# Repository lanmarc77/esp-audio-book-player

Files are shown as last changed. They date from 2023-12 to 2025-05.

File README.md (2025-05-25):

# TINAMP: An ESP32 based audio book player build from existing electronics modules
TINAMP: **T**his **I**s **N**ot **A** **M**usic **P**layer.  
  
This is a device that is meant to play non-DRM audio books from SD cards and has the following features:  

- folder based audio book player, one folder contains all files of one audio book
- multiple audio books supported (currently max. 9999 on one SD card with presorted index)
- sorting of audio book names and audio book files by ASCII name (see limitations of sorting below)
- saves audio book listening position and resumes for each audio book
- supports huge single file audio books, e.g. a 20hrs long singe file audio book
- file formats AMR-WB, MP3 and OGG
- ASCII character based menu driven UI for 16x4 character screen
- single rotary encoder navigation
- sleep timer 1...480min, wakeup timer 1min...24hr
- play speed settings from 0.5...2.5 in 0.05 steps (saved individually for each audio book)
- audio equalizer (saved individually for each audio book)
- endless auto repeat mode of selected audio book
- auto power off
- firmware upgrades from SD card
- based on pure esp-idf + esp-adf
- plays 50hrs+ with 2800mAh 18650 battery
- does not need nor use any wireless connection
- does not track the user in any way
- charging via USB-C
- endless options of integrations with speakers/cases
  
It tries to follow the design principle of
[doing one thing and doing that well](https://en.wikipedia.org/wiki/Unix_philosophy).
  
# The working prototypes
development board:
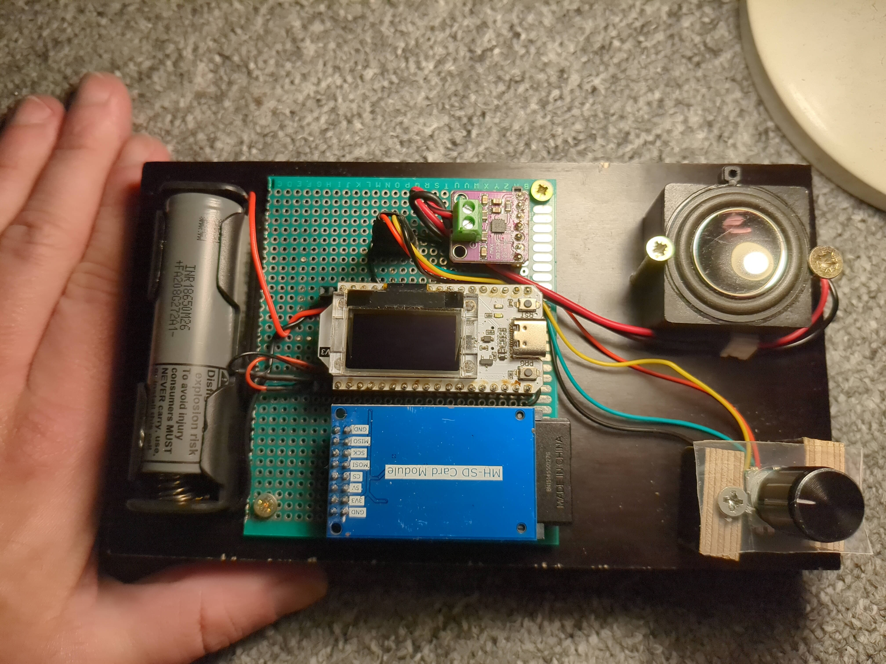
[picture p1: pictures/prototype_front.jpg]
  
  
integrated in an old speaker that otherwise might have landed in the trash:  
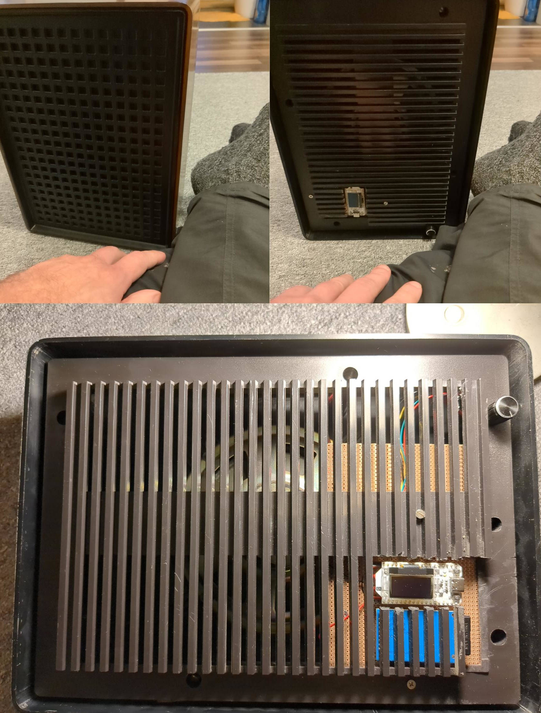
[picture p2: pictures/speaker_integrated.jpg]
  
  
the current portable/smaller prototype version (based on Hammond RL6215 case):  
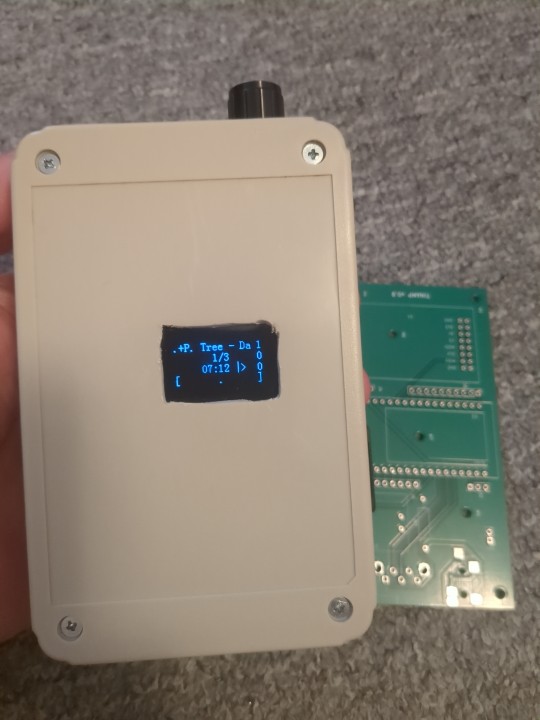
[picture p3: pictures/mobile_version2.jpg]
  
  
first 3d print prototype with 80s vibes:  
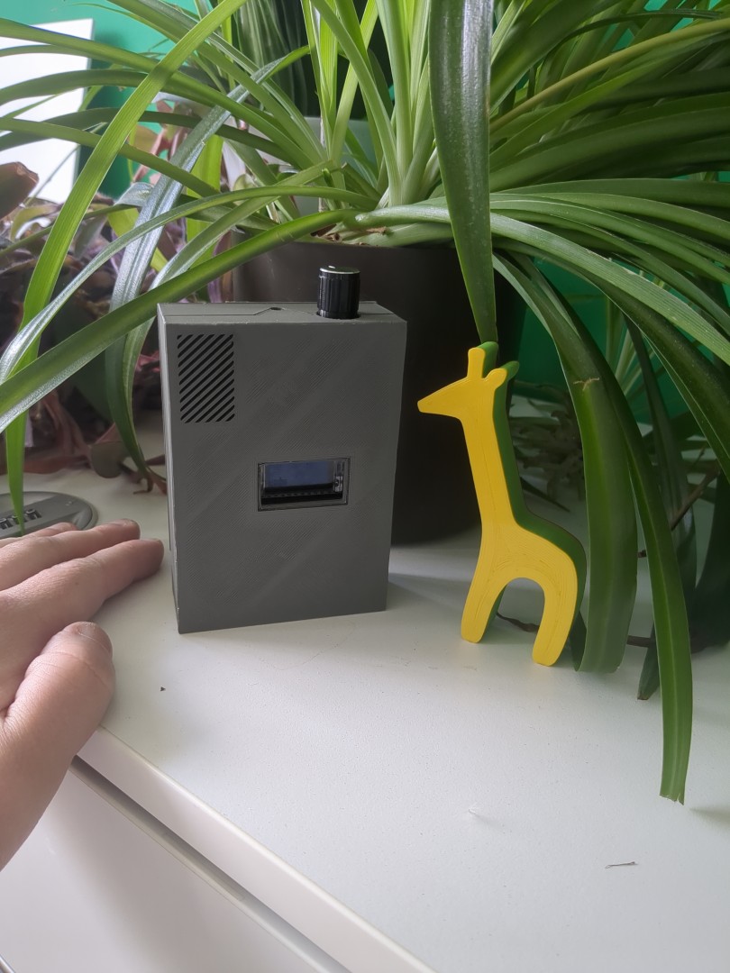
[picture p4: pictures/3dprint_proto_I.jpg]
  
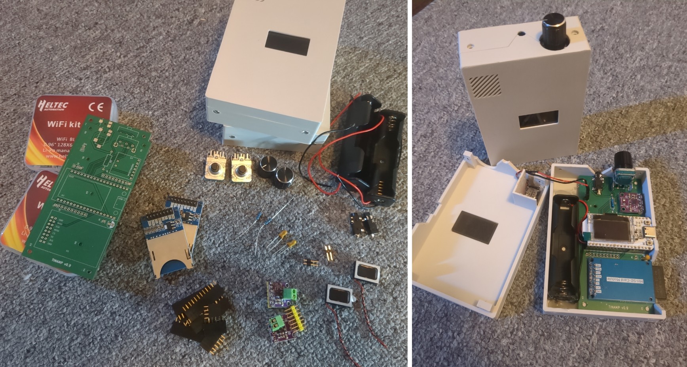
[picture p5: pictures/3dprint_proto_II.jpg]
  
  
[first POC (proof of concept)](pictures/first_poc.jpg)
  
# Why?
By the time of this writing (2023) one really needs to search hard to find an offline only non tracking audio book player that is
able to play files from huge SD cards and at the same time sorts the files based on their name and remembers and
resumes the last listening position.  
Many people nowadays will use subscription services with corresponding apps on their smartphone. These services
and the apps usually track the users build profiles suggest new audio books sell ads and more. Services like these can be canceled at any time. May it be for politics or economic reasons. They usually do not allow you to own the audio book but only sell a license to listen at it for as long as the company exists or is allowed to do business with you.  
I have an audio book collection that I created by only buying if I can download the files or copy them e.g. from a CD to keep them. Without any DRM.  
All my audio books are converted to and then stored in AMR-WB as for me the quality with 24kBit/s mono is good enough.
This shrinks an MP3 file to approx. 1/10ths when using AMR-WB and also makes the backup cheap. One CD with AMR-WB can hold 60hrs, a DVD 350hrs, a 25GB BD-R 2000hrs+.  
A 256GB SD card can hold around 2 years and 9 months of continuous listening in AMR-WB. Multiple SD cards can hold enough listening material for a life time.  
Using existing electronics hardware modules and the software of this repository I can now build a device that just plays my audio books. Not more, not less. And it most likely will do so in 30years assuming nothing breaks.
There are still 30yrs+ old Nintendo Gameboys that work like a charm and are being refurbished.  
Additionally I can change the behavior of the software as I like. The whole development environment works offline and can also be installed in an offline virtual machine and will still be able to compile even if the hardware manufacturer of the main controller board does not exist anymore.  
  
# Videos
Download and watch:  
[Scenario1](https://github.com/lanmarc77/esp-audio-book-player/raw/main/videos/scenario1.mp4): normal operation  
[Scenario2](https://github.com/lanmarc77/esp-audio-book-player/raw/main/videos/scenario2.mp4): seeking  
[Scenario3](https://github.com/lanmarc77/esp-audio-book-player/raw/main/videos/scenario3.mp4): sorting  
[Scenario4](https://github.com/lanmarc77/esp-audio-book-player/raw/main/videos/scenario4.mp4): auto bookmarks  
[Scenario5](https://github.com/lanmarc77/esp-audio-book-player/raw/main/videos/scenario5.mp4): sleep timer  
[Scenario6](https://github.com/lanmarc77/esp-audio-book-player/raw/main/videos/scenario6.mp4): wakeup timer  
[Scenario7](https://github.com/lanmarc77/esp-audio-book-player/raw/main/videos/scenario7.mp4): firmware upgrade  
[Scenario8](https://github.com/lanmarc77/esp-audio-book-player/raw/main/videos/scenario8.mp4): play speed, equalizer, repeat mode  
  
# Hardware
The build only needs a few components that are manufactured by companies in mass and therefore cheap.  
For PCB based components the schematics are available in the module datasheets folder.  
  
**Main controller board:**  
The main controller board is a Heltec WiFi Kit 32 V3. It was chosen because it has a very small deep sleep
current of about 10µA. I measured 15µA with nothing connected to it. Still very good. It already comes with
the circuitry to connect and charge a rechargeable battery as well as the possibility to disconnect other
components from power by using a software programmable power pin (Ve).  
Finally an OLED display is also already available for the UI.  
Be aware that you buy V3 of this board version as it has the low deep sleep current. Otherwise your battery
looses way too much energy even if you do not use the player. Additionally verify that you also get a fitting
battery cable.  
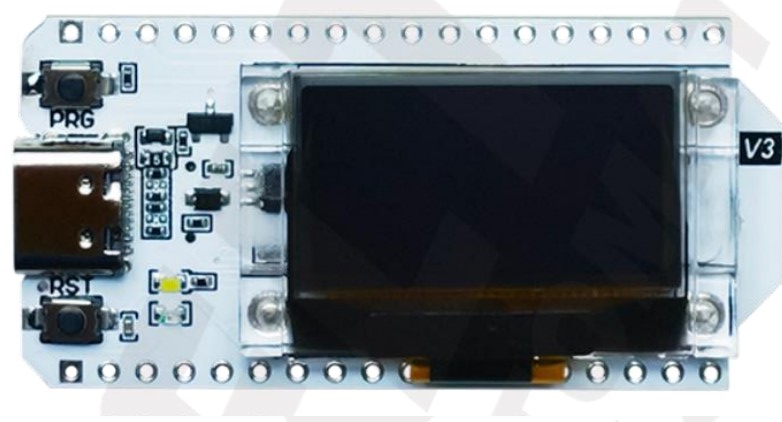
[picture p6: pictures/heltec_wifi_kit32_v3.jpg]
  
Typical price in Germany incl. tax (2023): 20€. 
  
**I²S digital analog audio converter**  
Currently only a MAX98357A based converter has been tested extensively. Also an UDA1334A and PCM5102 were
tested and they worked. Both of these stereo DACs needed around 10-15mA more current which will reduce the system
runtime.
The MAX98357A already contains an amplifier to directly connect it to a speaker and get a usable volume out
of it.  
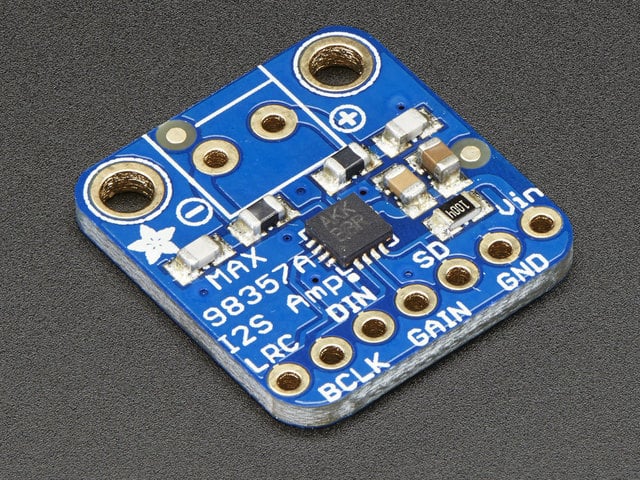
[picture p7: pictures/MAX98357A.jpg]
  
Typical price in Germany incl. tax (2023): 8€. 
  
**SD card holder**  
I still had old big SD cards laying around so I started with a big SD card holder. They also exists in
micro sd card format. I used this model as it comes with the needed pullup resistors already on the PCB.
Additionally I removed the voltage regulator that is used to convert 5V to 3.3V as I drive the board already
with 3.3V and it consumed around 2mA if back fed. I tested SD cards up to 512GB with this board and they worked.  
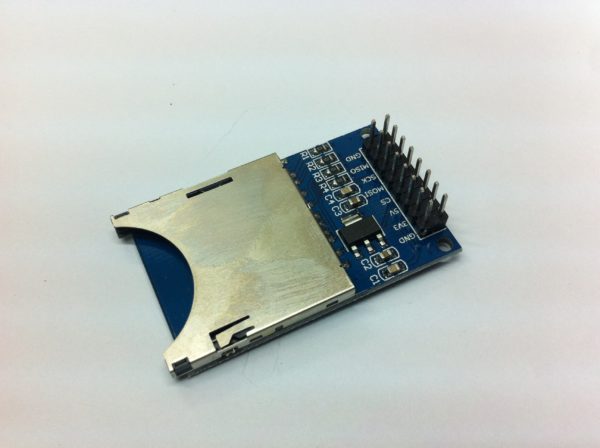
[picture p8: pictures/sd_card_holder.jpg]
  
Typical price in Germany incl. tax (2023): 1.5€. 
  
**Battery and holder**  
Any LiIon battery can be used. I tried 18650 and 14500 without any problems. I suggest trusted dealers as
there are many cheap fake batteries.  
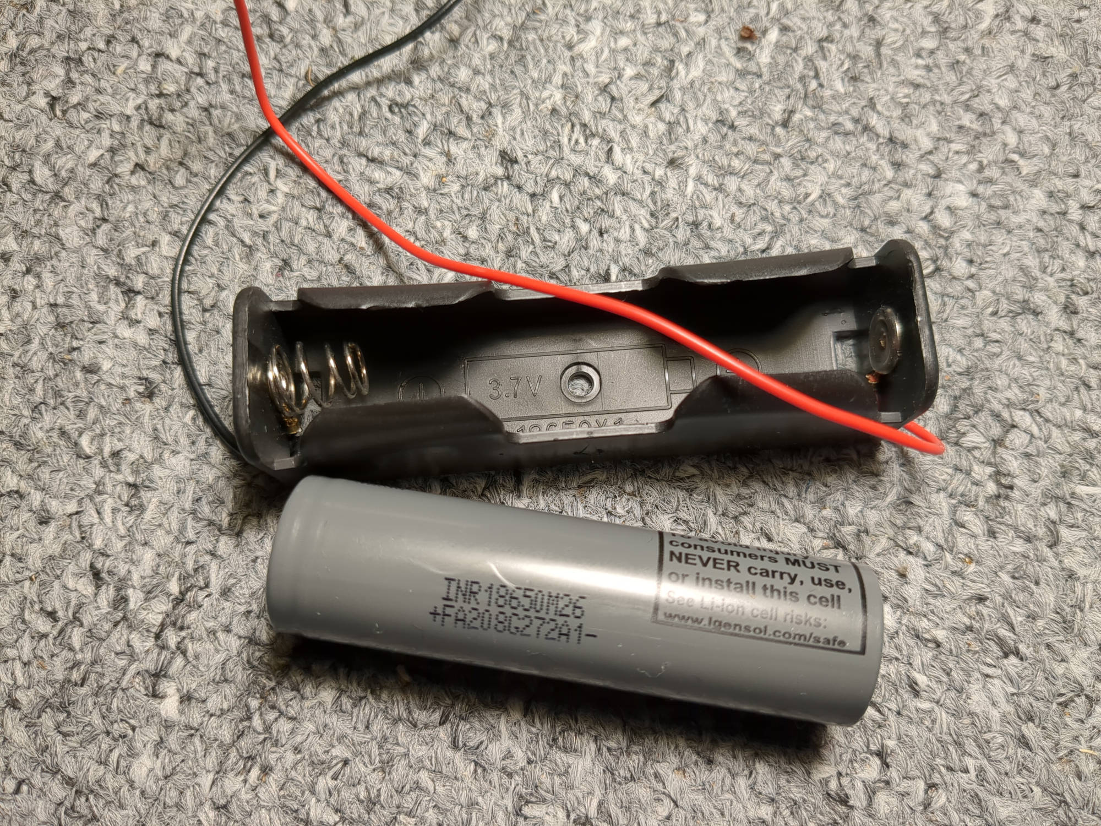
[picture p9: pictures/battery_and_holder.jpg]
  
Typical price in Germany for both incl. tax (2023): 8€. 
  
**Rotary encoder**  
To minimize wiring and drilling work I decided for a single rotary encoder as main navigation option. This model
has an integrated switch. I suggest to buy a version that comes with the washer/nut/cap.  
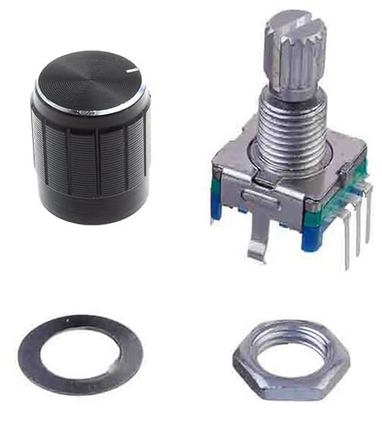
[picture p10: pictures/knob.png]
  
Typical price in Germany incl. tax (2023): 1€. 
  
**PCB**  
The prototypes as seen above use half or full size euro card PCBs. Any will do for manual wiring. You would
use the full size if you need the extra space for mounting it inside e.g. a speaker.  
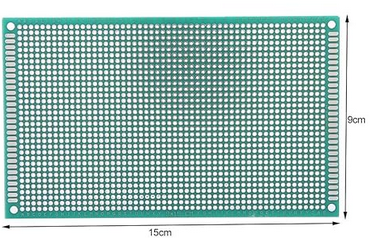
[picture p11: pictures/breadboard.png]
  
Typical price in Germany incl. tax (2023): 2€. 
  
## Wiring diagram
Click on the picture for zoom.  
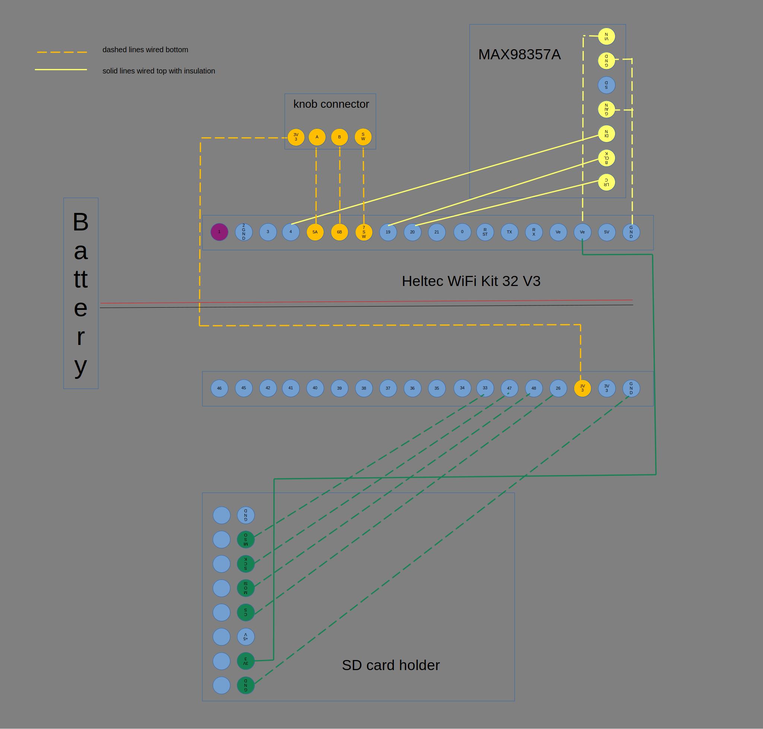
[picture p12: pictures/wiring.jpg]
  
  
The original .odt file of this drawing is in the `src`directory.  
  
Pictures of manually wired PCB:  
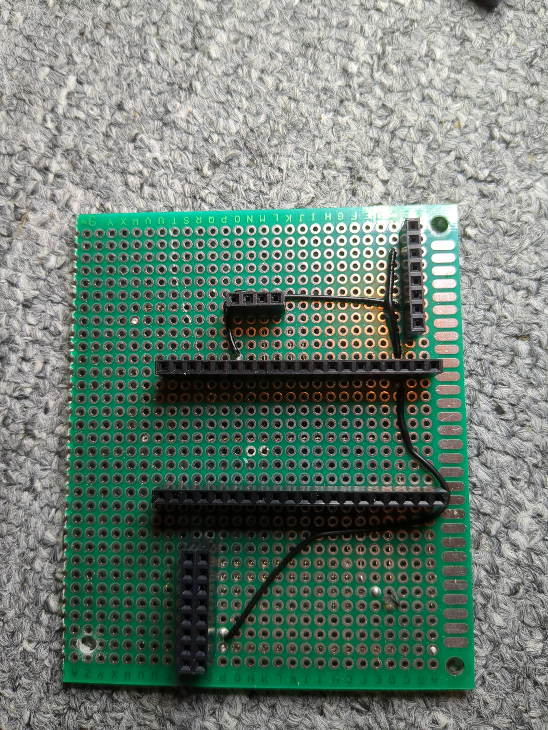
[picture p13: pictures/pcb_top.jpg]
  
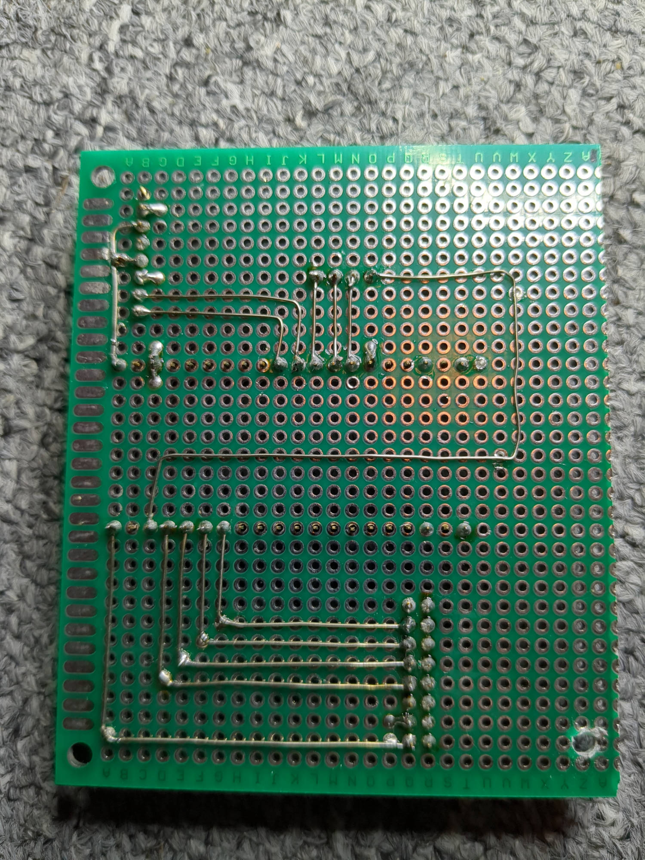
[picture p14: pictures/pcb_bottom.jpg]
  
  
These PCBs have headers for the components. You can leave these out but then need to make sure in 
which order you solder the wires as you might not get to them anymore.   
  
## Buyable manufactured PCB
WIP: One or two PCB layouts as motherboard for a 3D printed base case and a worldwide buyable case.  
First prototype PCB:  
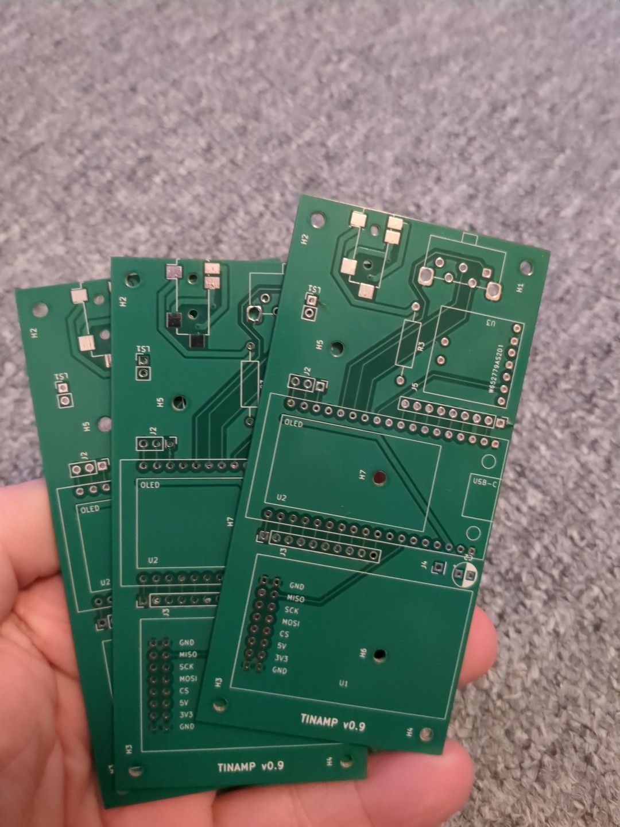
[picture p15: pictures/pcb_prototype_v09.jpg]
  
  
## Printed/buyable case
WIP: 3D case model  
TODO: worldwide buyable model (most likely the Hammond RL6215)  
  
## Current measurements / battery life
The runtime of the system is highly dependent on the current consumption. The current consumption depends on the
type of audio played and mostly the volume. The following measurements were made using the
setup prototype development board as seen above with 8 Ohm speaker OWS-131845W50A-8, 3.7V, 4GB class 10 Transcend
microSD. An UNI-T UT61E with a 22µF tantal smoothing capacitor to handle the current peaks was used. Play speed
setting x1.0.  

| scenario | volume setting  | current |
|---|---:|---:|
| switched off |  0%  | 19µA |
| switched on, not playing, display on |  0%  | 37ma |
| switched on, not playing, display off|  0%  | 34ma |
| 128kbit/s mp3 44100 khz | 50%  | 42ma |
| 64kbit/s mp3 44100 khz | 50%  | 42ma |
| 128kbit/s mp3 22050 khz | 50%  | 39ma |
| 64kbit/s mp3 22050 khz | 50%  | 39ma |
| 128kbit/s ogg 44100 khz | 50%  | 44ma |
| 64kbit/s ogg 44100 khz | 50%  | 44ma |
| 128kbit/s ogg 22050 khz | 50%  | 41ma |
| 64kbit/s ogg 22050 khz | 50%  | 41ma |
| 24kbit/s amr 16000 khz | 50%  | 41ma |
| 128kbit/s mp3 44100 khz | 75%  | 51ma |
| 64kbit/s mp3 44100 khz | 75%  | 51ma |
| 128kbit/s mp3 22050 khz | 75%  | 50ma |
| 64kbit/s mp3 22050 khz | 75%  | 50ma |
| 128kbit/s ogg 44100 khz | 75%  | 52ma |
| 64kbit/s ogg 44100 khz | 75%  | 52ma |
| 128kbit/s ogg 22050 khz | 75%  | 52ma |
| 64kbit/s ogg 22050 khz | 75%  | 52ma |
| 24kbit/s amr 16000 khz | 75%  | 52ma |
| any file from before | 100% | ~105mA |
  
At high volumes the energy needed by the speaker dominates the current consumption. Also the current is not very stable and highly depends on the content that is actually played.  
The volume setting follows an x⁴ curve for translating % into power to fit our hearing.  
Depending on play speed settings the current consumption rises. This is due to the fact that more data needs to be handled and the CPU frequency is stepped up. Approximately 2mA per 0.1 step speed up.  
  
Real life tests resulted in a runtime of 54hrs:05mins playing 24kbit/s amr audio on QKZ AK6 earphones at 50% volume with a Murata / Sony Konion US18650VTC5D 2800mAh battery on firmware v00.00.08 (normal speed, no equalizer) from a 256GB Transcend SD card. A full charge after this test took 5hrs:15mins.  
  
# UI and player navigation
The following sub chapters explain the states of the player and the different menus or screens the player shows.  
You might want to watch the videos above for a short(er) introduction.  
  
The most common use case of an audio book player is powering it on, resume playing (maybe pause from time to time) and switching it off. This is currently done by pressing the rotary knob (for power on) which takes around 2s to right away jump into the last listened audio book and listening position, followed by another press of the rotary knob to start playing. Pressing the rotary knob while playing will pause the audio book player (and saves the listening position). Leaving it paused for 60s will power off automatically.  
  
## The rotary encoder
The only input device is a rotary encoder with a button. They are usually used as:  
  
- rotation for number, time and volume selections, speed of rotation in most menus increases the step size of the setup unit
- short click usually used for ok
- long click usually used as back, stop or cancel
- double click activates sub or special functions

## The players state machine
Legend:  
SC=short click  
LC=long click (or wait 10s in reduced functions mode)  
DC=double click  
AC=any type of click  
  
```
            powered off
                |
                | AC
                |                                              pressed long
                v       button still pressed?                    enough?   
            init screen ---------------------> reset countdown ---------- 
                |                                 screen                 |
                |                                    | button            |
                |                                    | released     reset screen
                |                                    |          +delete all bookmarks
                |                                    |            and user settings
                |                                    |                   |
                |                                    v                   |
                |<-------------------------------------------------------
                |
                | no sd card found?                      3s
                |--------------------> no sd card screen ---> power off
                |
                | new fw upgrade found?           SC                      10s
                |------------------> upgrade init ----> upgrade countdown --
                |                      screen              screen           |
                |                        |                  |               |
                |                        | any other        | AC         upgrade
                |                        | click            |            progress
                |                        | or no click      |            screen
                |                        v after 3s         v               |
                |<------------------------------------------                | ~10s
                |                                                           |
                |                                                           v
                |                                                         reboot
                |
                | ~2s
                v           0 folders?                               3s
          audio book scan -------------> no audio books found screen ---> power off
              screen
                | ~?s
                | scan time depends on number of audio books
                |
                v                    LC                                  3s
   ---> audio book selection screen ----> persist new fw ---> off screen ---> power off
  |     |     |       ^    ^      ^         if needed
  |     |     |SC     |    |      |
  |     |     |       |    |      |
  |     |     |       |    |      |
  |     |     |       |    |      |
  |     |     |       |     ----   -
  |     |     |       | AC      |   |
  |     |     v       |         |   |<-------------------------
  |     |    audio book content |   |                          |
  |     |    |   scan screen    |   |                          |
  |     |    |    |             |   |       next sub screen    |
  |     |    |    | 0 files     |   |       ---------------    |
  |     |    |    | found?      |   |      |               |   |
  |     |    |    |             |   |      v            SC |   |
  |     |    |     -------------    |    play overlay ----     |
  |     |    |                      |    screen                |
  |     |    | scan      -----------     |3s  ^                |
  |     |    | finished |                |    | rotate         |
  |     |    |          | LC             |    |                | LC
  |     |    v          |       SC       v    |       SC       |
  |     |    pause screen  <----------> playing <-----------> pause screen
  |     |    with chapter  <----------  screen <------         with time
  |     |     selection            LC     |           |        selection
  |     |                                 | DC        |
  |     |                                 |        play next
  |     |                                  -------> chapter
  |     |
  |     |
  |     | select audio book "0"
  |     |  named setup screen
  |      -----------------
  |                       |          next settings
  |      LC               v             screen
   ---------------- global settings <--------------
                      ^   |     |           rotate |
                      |   | SC   ------------------
      ----------------    |
     |                    |
     |                    v                change value
     |           any chosen setup screen <--------------
     |           |              |  |            rotate  |
     |           | SC           |   --------------------
     |           | means ok     |
     |           |              | any other
     |           | for wakeup   | click cancels
     |           | timer:       | for wakeup timer:
     |           | activated    | deactivated
     |           v              |
      --------------------------

```

After 30s of no click the screen turns off. If the player is not playing and the screen was off for an additional
30s then the player powers off.  
If the screen is off any click will first turn the screen on. An additional click is needed for the desired action. There is one exception: the double click in the play screen to skip to the next chapter works right away even if the screen is off.  
If the battery level drops below 3.35V the low battery screen is shown and the player powers off.  
  
## The menus
All menus are built upon the basic ASCII set. This should allow changing the display easily.  
If something can be setup using rotation usually that element flashes.  
  
### Init screen
```
 ----------------
|                |
|     (o_o)      |
|       ok       |
|   v00.00.08    |
 ----------------
```
Shows the firmware version number. If ok is displayed the firmware is persisted. If TEST is displayed
the firmware is not persisted and if the player powers off automatically the old firmware is reinstalled.  
  
### Reset countdown screen
```
 ----------------
|                |
|     (o o)      |
|       O        |
|[=========-    ]|
 ----------------
```
If the button is hold down until the progress bar at the bottom has counted down the player
will delete all bookmarks and reset all user settings to default values.  
  
### Reset screen
```
 ----------------
|0000000000000000|
|0000000000000000|
|0000000000000000|
|0000000000000000|
 ----------------
```
Shown until the reset procedure is finished.  
  
### Upgrade init screen
```
 ----------------
| ||    00.00.07 |
|-  -     vvv    |
|-  -      ?     |
| ||    00.00.08 |
 ----------------
```
Shows the currently installed firmware and the new version that can be installed.  
  
### Upgrade countdown screen
```
 ----------------
| ||    00.00.07 |
|-  -     vvv    |
|-  -     5s     |
| ||    00.00.08 |
 ----------------
```
A countdown counts down to signal the upgrade will be started.  
  
### Upgrade screen
```
 ----------------
|       ||       |
|    -  34% -    |
|    -      -    |
|       ||       |
 ----------------
```
Progress is shown during the running upgrade procedure.  
  
### No SD card screen
```
 ----------------
|    -------     |
|   | SD ?  |    |
|   |______/     |
|                |
 ----------------
```
This screen is also shown if the SD card is removed while the player is active.  
  
### Audio book scan screen
```
 ----------------
|     |---|      |
|     | ? |      |
|     |---|      |
|[===    .      ]|
 ----------------
```
The progress bar at the bottom shows the progress of the scan an sorting process.  
  
### No audio books found screen
```
 ----------------
|     |---|      |
|     | 0 |      |
|     |---|      |
|                |
 ----------------
```
### Audio book selection screen
```
 ----------------
|audio book name |
| |------------| |
| |     12/121 | |
| |*---00:01---| |
 ----------------
```
Using rotation the different audio books can be selected. The screen shows selected 12 of 121 audio books.
The audio book name at the top is the name of the folder and scrolls through the screen if it is long.  
The value 00:01 is only shown if the wake up timer has been setup and activated and shows the setup value.  
If an ```!``` is shown it means a bookmark exists for this book. If an ```*``` is shown the bookmark is at a position >95% of the last track of this book.  
  
### Audio book content scan screen
```
 ----------------
| |------------| |
| |  A <==> B  | |
| |------------| |
|[=====- .      ]|
 ----------------
```
The progress bar at the bottom shows the progress of the scan and sorting process and A and B are animated.  
The sorting can be canceled if it takes too long by using any click.  
  
### Pause screen
```
 ----------------
|audio book name |
|      3/12 3m  8|
|     12:22 |>  9|
|[===-   .      ]|
 ----------------
```
The audio book name at the top is essentially the name of the folder and scrolls through the screen if it is long.  
3/12 shows the currently selected chapter (=file) of this audio book and the number of all chapters.  
12:22 is the current time within the currently selected chapter.  
Depending on the mode either the time or the chapter flashes meaning this can be changed (seek or skip) using rotation.  
The value 3m is only displayed if a sleep timer was setup and activated and shows the time left until the player will power off.  
The progress bar at the bottom shows the progress within the current chapter.  
On right side the battery level in percent is shown.  
    
### Playing screen
```
 ----------------
|audio book name |
|      3/12 3m  8|
|     12:22 ||  9|
|[===-   .      ]|
 ----------------
```
The audio book name at the top is essentially the name of the folder and scrolls through the screen if it is long.  
3/12 shows the currently selected chapter (=file) of this audio book and the number of all chapters.  
12:22 is the current time within the currently selected chapter.  
The time is switching repeatedly between current time position and time left.  
The value 3m is only displayed if a sleep timer was setup and activated and shows the time left until the player will power off.  
The progress bar at the bottom shows the progress within the current chapter.  
On right side the battery level in percent is shown.  
If an asterisk ```*```  is shown beside the pause symbol ```||``` then repeat mode for this audio book is active.  
Sometimes a countdown is shown in the middle of the progress bar. It counts the amount of seconds left until the play overlay screen sub menu position is switching back to volume.  
  
#### Play overlay screen
```
     volume               sleep timer
 ----------------      ----------------  
|################|    |                |
|################| -> |    (-_-)Zzz    |
|##              |    |      1/99m     |
|      5100      |    |                |
 ----------------      ----------------
        ^                     |
        |                     v
        |                 play speed
        |              ----------------  
        |             |                |
        |             |     >>>>>>>>   |
        |             |      x1.20     |
        |             |                |
        |              ----------------
        |                     |
        |                     v
  repeat mode              equalizer
 ----------------      ----------------  
|                |    |                |
|  |>  -->  ||   | <- |     normal     |
|                |    |                |
|                |    |                |
 ----------------      ----------------
```
The play overlay screen is activated when a file is played and the rotary encoder is turned. If it is active a short click is going through the different settings. This screen will automatically switch back to the play screen after 3s of no user input but will remember for 8 more seconds at which sub menu it was left.  
  
Volume: The # characters are a visual representation of the setup volume. Volume level ranges from 0...10000. 7500 actually marks 100% audio volume of the source everything above this will add a gain of up to 25% to the source volume level.  
  
Sleep timer: Using rotation the sleep timer can be setup from 1 minute to 99 minutes in minute precision. Time automatically starts if a value is setup and is canceled if - is displayed.  
  
Play speed: Using rotation the speed can be setup. Play speed is changed instantly and stored individually for each audio book.  
  
Equalizer:  Using rotate you can choose between the different equalizer presets. The setting is stored individually for each audio book.  
  
Repeat mode:  Using rotate one can choose to enable folder repeat (<-->) or not (-->). The setting is stored individually for each audio book.  
  
### Low battery screen
```
 ----------------
|      _--_      |
|     |    |     |
|     |    |    6|
|     |####|     |
 ----------------
```
On the right side the battery level in percent is shown.  
  
### Off screen
```
 ----------------
|                |
|    (-_-)Zzz    |
|    241160MB    |
|     15/2%      |
 ----------------
```
Also shows the size of the detected SD card, the number of stored bookmarks and the used space of the bookmark storage in the SPIFFS of the ESP32.  
  
### Global settings/functionality
The setup is entered by scrolling to audio book "0". The following screen is displayed:  
```
 ---------------- 
|     *******    |
|   /  Setup  \  |
|   \         /  |
|     *******    |
 ----------------
```
Setup is entered with a single click and left with a long click.  
It has the following internal layout:  
```
   wakeup timer         screen rotation
 ----------------      ----------------
|       1/8      |    |       2/8      |
|(-_-)  ->  (o_o)| -> |   -------->    |
|                |    |  |    0    |   |
|      01:00     |    |   <--------    |
 ----------------      ----------------
        ^                     |
        |                     v
     firmware           screen brightness
     persist               settings
 ----------------      ----------------
|       8/8      |    |       3/8      |
|     persist    |    |\\\\\\    //////|
|     firmware   |    |       100      |
|        ?       |    |//////    \\\\\\|
 ----------------      ----------------
        ^                     |
        |                     v
     reduced           rotary encoder
      mode                direction
 ----------------      ----------------
|       7/8      |    |       4/8      |
|       all      |    | o o            |
|    functions   |    |o   o    -->+   |
|                |    | o o            |
 ----------------      ----------------
        ^                     |
        |                     v
     bookmark           rotary encoder
     deletion               speed
 ----------------      ----------------
|       6/8      |    |       5/8      |
|   Bookmarks    | <- | o o            |
|    10 -> 0     |    |o   o     x1    |
|       ?        |    | o o            |
 ----------------      ----------------
```
After entering the global settings the rotary knob can be used to select the setting to change.  
A short click will enter the specific setting selected.  
On top a counter for all settings is shown.  
If this menu is left with a long click all settings that are saveable are saved.  
  
#### Wake up timer setup screen
```
 ----------------
|                |
|(-_-)  ->  (o_o)|
|                |
|      01:00     |
 ----------------
```
Using rotation the wakeup timer can be setup from 1 minute to to 24 hours in minute precision.  
This setting is not stored. It always starts with 1 hour after the player started.  
Once the timer was activated its setup time starts counting **after** the player was shutdown independent if the shutdown was initiated manually or by a sleep timer.  
  
#### Screen rotation setup
```
 ----------------
|                |
|   -------->    |
|  |    0    |   |
|   <--------    |
 ----------------
```
This allows rotating the screen by 180°. 0 stands for default and 180 for 180° rotated setting.  
This setting is stored and reloaded on each player start.  
  
#### Screen brightness setup
```
 ----------------
|                |
|\\\\\\    //////|
|       100      |
|//////    \\\\\\|
 ----------------
```
This allows to setup the brightness of the screen. Step size is +/-5 and ranges from 0 to 250.  
This setting is stored and reloaded on each player start.  
  
#### Rotary encoder direction setup
```
 ----------------
|                |
| o o            |
|o   o    -->+   |
| o o            |
 ----------------
```
This allows switching the turn direction of the rotary knob. Left turns are getting right turns and vice versa.  
This setting is stored and reloaded on each player start.  
  
#### Rotary encoder speed setup
```
 ----------------
|                |
| o o            |
|o   o     x1    |
| o o            |
 ----------------
```
This allows changing the speed of the rotary knob. One can choose that every dent of the rotary encoder is used (x1) or only every 2nd dent (x0.5).  
This setting is stored and reloaded on each player start.  
  
#### Bookmark deletion
```
 ----------------
|                |
|   Bookmarks    |
|    10 -> 0     |
|       ?        |
 ----------------
```
Shows the number of bookmarks that can be deleted using a short click without deleting other settings.  
  
#### Reduced functions mode
```
 ---------------- 
|                |
|       all      |
|    functions   |
|                |
 ----------------
```
If reduced functions only the normal single click is an accepted rotary knob action. The long press (usually back) of the rotary knob is disabled and instead substituted by a 10s time delay. If 10s nothing is pressed the menu is automatically left.  
Additionally the overlay only allows setting up volume with no further sub menus like play speed. Also no double click is accepted.  
This mode is meant for elderly persons who might have difficulties with all the possibility and just want to select and audio book and listen to it.  
  
#### Firmware accept
```
 ---------------- 
|                |
|     persist    |
|     firmware   |
|        ?       |
 ----------------
```
If the firmware was just upgraded the firmware can be kept with this menu point. If the firmware was persisted already it shows OK instead of a question mark.  
If the firmware is not persisted after an upgrade and the player is shutdown the player will rollback the firmware to the previous one.  
  
# Uploading initial binary release
For a brand new main controller board an initial upload is needed. This initial upload will setup the correct partition details and installs the firmware for the first time. After this initial upload firmware upgrades via the SD card are possible.  
The binary release files in the [release](https://github.com/lanmarc77/esp-audio-book-player/releases) section:  
  
- bootloader.bin
- partition-table.bin
- ota_data_initial.bin
- esp32_player.bin
  
are to be used for this initial upload.  

## Linux and Windows
For Linux and Windows the Espressif esptool.py can be used. It can be installed by following [this guide](https://docs.espressif.com/projects/esptool/en/latest/esp32/).  
A Windows Comport driver can be found in the `src` directory.  
  
The command line for the initial upload should look like this:  
`
esptool.py -p [YOUR PORT e.g. COM7 or /dev/ttyUSB0] -b 460800 --before default_reset --after hard_reset --chip esp32s3 write_flash --flash_mode dio --flash_freq 80m --flash_size 4MB 0x0 bootloader.bin 0x10000 esp32_player.bin 0x8000 partition-table.bin 0xd000 ota_data_initial.bin
`  
  
Since v00.00.03 firmware upgrades are possible via SD card if this initial upload was done.  
  
## Windows using the Flash Download Tools
Espressif also offers the Windows only Flash Download Tools package with a graphical user interface.  
It can be downloaded from [here](https://www.espressif.com/en/support/download/other-tools).  
A Windows Comport driver can be found in the `src` directory.  
  
The following settings need to be made for the initial upload:  
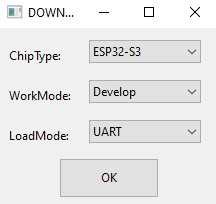
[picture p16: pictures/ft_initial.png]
  
Select the correct COM port after making the settings as seen below and press START:  
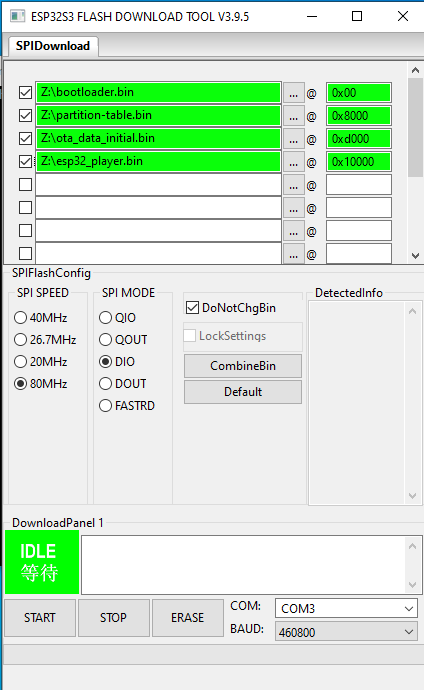
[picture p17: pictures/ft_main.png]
  
Ideally no errors are shown and the initial upload is finished.  
  
# FW upgrade using SD card (incl. rollback support)
For upgrading firmware once the initial upload was done only one specific file from the
[release section](https://github.com/lanmarc77/esp-audio-book-player/releases) is needed: XX.XX.XX_ota.fw  
XX are letters from A-F or/and numbers from 0-9 specifying the firmware version of this release.  
Place the file on the SD card in a folder called `fwupgrade`. Once you start the device it should present you with the upgrade screen. The upgrade screen is left without upgrading if no user interaction is happening for 10s.  
If you wish to upgrade shortly press the encoder button. A countdown of 10s gives you the possibility to stop the upgrade if you press the encoder button. Once the upgrade started you can not interrupt it.
The actual writing process for the upgrade takes around 10s and the progress is shown.  
  
If everything worked you should now see the device restart with the new firmware version but it displays
"TEST" instead of "ok" in the initial firmware version screen during startup.  
"TEST" means that the new firmware is not yet persisted. In this test state you have the possibility
to test everything and check if the new version suits your needs.  
You can persist the new firmware by manually switching the device off by long pressing the encoder button
in the audio book selection screen.  
If you do not want to keep the new version and rollback you need to wait for the
device to auto power off which usually happens after 1 minute with no user interaction. Once auto powered off and
afterwards started again the old version should be activated again.  
  
# Compilation hints
Currently used espressif sdk versions:  
esp-idf:  v5.3.2/commit 9d7f2d69f50d1288526d4f1027108e314e8c879f  
esp-adf:  v2.7/commit 9cf556de500019bb79f3bb84c821fda37668c052  
  
Needed for exFAT:   
To enable exFAT file esp-idf/components/fatfs/src/ffconf.h needs to be adjusted.  
  
Optionally for more privacy:  
The esp-adf unnecessarily links components which on every compilation results in checks with the servers for updates by the component manager.  
To be able to compile completely offline adjustments to the sdk source trees were made.
  
Take a look into the `src/patches/` directory for the .patch files to apply to above sdk versions.
  
# Software architecture
  
```

 -----------------
|   ssd1306*.*    |           -----------------------
|                 |          |       battery.*       |
| low level I²C   |          |                       |
| functions for   |          | monitors, filters     |
| OLED and fonts  |          | and offers the        |
|                 |          | current battery level |
 -----------------           |                       |
         ^                   | uses task             |
         |                   |                       |
         | calls              -----------------------
         |                     ^
 --------------------          |
|   ui_elements.*    |         | calls
|                    |         |
| offers reusable    |         |
| UI elements        |         |                                   --------------------------
|                    |         |    ---------------------------   |         sd_play.*        |
 --------------------          |   |     rotary_encoder.*      |  |                          |
           ^                   |   |                           |  | plays files from SD card |
           |                   |   | low level rotary encoder  |  | using esp-adf pipelines  |
           | calls             |   | and switch handling       |  |                          |
           |                   |   |                           |  |                          |
 ------------------------      |   | uses task + interrupt     |  | uses tasks               |
|       screens.*        |     |   |                           |  |                          |
|                        |     |    ---------------------------    --------------------------
| creates and displays   |     |     ^                              ^                      |
| complete screen        |     |     |                              |                      |
| layouts                |     |     | calls                        | calls                |
|                        |<-   |     | queue communication          | queue communication  |
 ------------------------   |  |     |                              |                      |
                            |  |     |           -------------------                   ----
                      calls |  |     |          |                                     |
                            |  |     v          v                               calls |
 -----------             --------------------------                                   v
|   main.*  |           |        ui_main.*         |             --------------------------
|           |  calls    |                          |            |      format_helper.*     |
|  basic    | --------> |    main player logic     |    calls   |                          |
|  board    |           |                          | ---------> | functions to get audio   |
|  init and |           |   state machine based    |            | format specific          |
|  deinit   |           |                          |            | information like         |
|           |           |                          |            | runtime and bitrate      |
 -----------            |                          |            |                          |
                        |                          |             --------------------------
       ---------------- |                          |
      |                 |                          |<-----------
      |                  --------------------------             |
      |                                |                        |
      | calls                          | calls                  | calls +
      |                                |                        | queue communication
      v                                v                        v
 --------------------         ----------------------         -----------------------------
|     sd_card.*      |       |        saves.*       |       |        ff_handling.*        |
|                    |       |                      |       |                             |
|  low level SPI     |       | handles save         |       | reads and sorts dirs/files  |
|  bus handling and  |       | restore and house    |       | an returns sorted lists     |
|  VFS mount/umount  |       | keeping of bookmarks |       |                             |
|                    |       | and player settings  |       | uses task for sorting       |
 --------------------        |                      |       |                             |
                              ----------------------         ------------------------------

```  
The following sub chapters will give an insight into each shown component and its architecture ideas.  
This layout shows the ideal model that only very rarely is broken in the code.  
  
## main.*
The entry point of the application. It initializes the board and sets up the CPU, disables WiFi and
hands over to the other components.  
Function main() is never left but if other components finish powers off the board and sets up a
wake up timer if needed.  
  
## ui_main.*
This component implements the main player logic. A state machine represents the navigation of the user
and the state the player is currently in.  
As the central component it makes direct use of a all the other components.  
  
## sd_card.*
This component initializes the SPI bus for usage with an SD card and tries to mount the SD card
into the ESPs VFS so it can be used by all other components using file access functions.  
  
## rotary_encoder.*
This component initializes and monitors the rotary encoder and switch using a task and and interrupt.  
Events are generated and placed as messages into a queue for communicating with other components.  
  
## battery.*
This component initializes and monitors the AD converter for monitoring the battery level.  
There are two battery levels available. With slower noise filtering and with faster more noisy filtering.  
A task samples the battery voltage every 500ms.  
  
## screens.\*, ui_elements.\*, ssd1306\*.\*
This collection of components uses a typical layered approach.  
The ssd1306 functions give access to a physical display. Here the OLED of the board.  
The ui_elements functions use the ssd306 functions to offer reusable UI elements like text output or
progress meters with which larger screen layouts can be built.  
The screens functions use the ui_elements functions to create a complete screen layout for the player.  
It is assumed that the display can handle a layout of 16x4 ASCII characters.  
  
## saves.*
This component handles the storage, retrieval and house keeping of bookmarks and the settings (like volume)
if the player. It makes use of the ESP VFS system and currently stores everything in the internal SPIFFS.  
It also takes care of initializing the SPIFFS.  
  
## ff_handling.*
This component scans folders and files within folders and delivers a sorted list. It uses a task for the
longer running scanning and sorting process and communicates its progress via a queue. The scanning and
sorting process can also be canceled via queue communication. During scanning and sorting the CPU
frequency is increased to speed up the process.  
  
## format_helper.*
This component offers audio file format functions. One can convert byte position <-> time stamp and
determine sample rates and bitrates and further information to setup the esp-adf pipeline correctly
right from the start.  
  
## sd_play.*
This components tries to abstract all the esp-adf functionality of playing an audio stream with in the pipeline.
It combines SD card access by allowing to start playing a file from the SD card using a task.  
Using queues the components can be instructed to start/stop the playing and contentiously reports the current
playing position for the user interface.  
The resume function that actually is not out of the box supported by a pipeline based streaming approach is
implemented by adding an own file stream handler within the pipeline that takes care of at first delivering needed
header information for the decoder but then jumps within the file to the position to resume from.  
  
## naming conventions
Filenames and global variables/functions match each others prefixes to easily be able to locate them.  
Prefixes are written in capital case and use _ as separator.  
Apart from the prefixes variables and functions use camel case.  
  
# Limitations, design decisions and behavior descriptions
The following sub chapters explain a few design decisions, limitations and system behavior.  
  
## Sorting, limits of files/folders
Sorting on a µC is hard. Sorting algorithms trade speed with memory and memory is something a µC usually does not have
very much. It is impossible to keep a huge root directory in memory depending on the the character length of each
entry. Especially if you want to be deterministic on how many entries you support.  
This projects implementation has two options of displaying and playing sorted entries.  
  
### Sorting each time
This is the default implementation. After startup when the list of all available audio books is read this list is sorted.
Instead of keeping the strings/names of all entries in memory only their file allocation table position is used. This position acts as kind of ID of the entry. This ID is then sorted inside an array but not by its value but by its corresponding name.
This means that the algorithm always has to translate between ID and name of the file resulting in an increased
time of sorting. The algorithm used is a selection sort with a complexity of O(n²). But it is memory deterministic.  
This allows keeping 1000 entries with only 2kB of memory usage. To always wait for 1000 entries to be sorted is also still acceptable.  
Sorting speed is also determined by the way entries are named. As the C function strcmp is starting to compare at the beginning of a string the earlier a mismatch happens the earlier it can stop. It is beneficial to name files e.g. 01... , 02... instead of ...01, ...02.  
If a directory contains more than 1000 entries they are not taken into account.  
This described sorting applies for audio books (directories) and their content (files).  
  
### Presorted list of root directory
As I wanted the player to be able to also hold large collections of audio books 1000 entries in the root directory did not seem enough.  
But sorting would take too long to be acceptable. Instead a presorted entry list can be created. Much like an .m3u file.  
The file needs be called `presorted.txt` and must reside in the root directory of the SD card. It can contain 9999 lines where each line contains the directory name. The order in the file is the order in which they are displayed in the player.  
The following command chain can be used in the root directory of the SD card to create such a sorted file:  
  
`find * -type d -print | sort | iconv -t 437 > presorted.txt`  
  
Names of entries are expected to be in code page 437 format as this is the only one that is enabled in the ESP32. I did not wanted to make things more complicated by supporting all kinds of character encodings.  
9999 entries=audio books with an average length of an audio book of 6hrs would take almost 55 years of listening if you listen every single day for 3hrs.  
  
For this 9999 entries limit to kick in:  

-  for AMR-WB file format with 24kbit/s an SD card would need to have ~618GB  
-  for MP3 file format with 128kbit/s an SD card would need to have ~3.3TB  

This implementation limit should not be relevant much while using the player.  
  
As the number of files within a directory/audio book are usually below 1000 the presorted.txt is not implemented for these.
  
## Bookmarks
I decided to implement the bookmark storage inside the SPIFFS of the ESP32. I reserved 512kB for the SPIFFS. The
storage could also have been the SD card and would have been the first choice. But that would mean writing to the
SD card. The same card where the audio books are stored. I did not wanted to risk file system problems if one of those
writes failed. Meaning a destroyed file system not being able to listen to audio books anymore. This project never
writes to the SD card which in turn never can get corrupted.  
Each bookmark is written when the player is paused or is powered off by one of the automatic methods like low battery
or sleep timer. A bookmark is a file in the SPIFFS. The name of the file is an MD5 hash constructed from the directory
name of the audio book. Inside the bookmark the listening position is stored and the file name that was currently played.  
  
Depending on the length of the file name bookmarks take more or less space in SPIFFS. On average 1kb can be assumed. This means around 500 bookmarks can be stored. Deleting individual bookmarks is not possible. To delete all bookmarks one can use the overall reset procedure or starting with firmware v00.00.08 the global settings menu, sub menu delete bookmarks.  
The powering off screen displays the usage of the SPIFFS in percent and the number of bookmarks.  
There is also an automatic bookmark deletion procedure implemented. If the SPIFFS usage level is above 75% the currently used SD card and the bookmarks are scanned and compared. If there are bookmarks in the SPIFFS for which no fitting directory on the SD card exists this bookmark is deleted. This house keeping idea is based on the use case that SD cards are being rewritten over and over with new audio books where the old ones are deleted. Ideally for this use case one should never be needed to manually delete old bookmarks.  
  
Manual bookmarks are not supported. Mainly because I personally never needed them but also because house keeping gets
much more complicated as well as a method of jumping to different bookmarks inside the same audio book must be implemented.  
  
## CBR/VBR
Only fully supported are CBR encoded files. The player also plays VBR files but the displayed timestamps might be wrong.
Without scanning the full file or implementing code for the various VBR indexes there is no way to determine a correlation of file position and time.  
The format handler functions take a look at the first frame of a file to determine the bitrate and therefore the frame length of a file. This data is then assumed to be valid for the whole file.  
  
## Metadata
No metadata of files is used. This includes chapter indexes, subtitles or cover pictures.  
  
## Bluetooth audio
The used µC board uses the ESP32-S3. This newer model of the ESP32 does not support the so called classic Bluetooth
audio stack which uses SBC as codec. It only supports the not yet widely used Bluetooth Audio LE. The esp-adf does
not yet support a pipeline element that uses Bluetooth Audio LE. Once support is added in the esp-adf pipeline system and devices are getting more common I might implement support for it.  
It might also be possible to make this project compile with the classic ESP32 that does support classic Bluetooth using SBC.
But I do not plan for this as I use headphones with a jack and no extra battery I need to take care of.  
  
## Audio processing
The ESP32 starts with the lowest possible CPU speed of 80Mhz. This is not enough CPU power if certain audio processing
options are enabled. Especially if the play speed has a high setting 80Mhz is not enough for the calculations needed. 
The program increases CPU speed to 160Mhz when play speed is getting greater than 1 and to 240Mhz for value greater 2.
This will increase power consumption and reduce system runtime.  
  
# Ideas/future
- multi user support with individual bookmarks
- audio navigation for handicapped people
- refactoring of code especially the huge ui_main.c

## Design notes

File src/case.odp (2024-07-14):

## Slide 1

2W Power

2500mAh

OpenSource

Super OLED

Auto Poweroff

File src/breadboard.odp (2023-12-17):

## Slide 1

LRC

BCLK

DIN

GAIN

SD

GND

VIN

dashed lines wired bottom

MAX98357A

solid lines wired top with insulation

knob connector

3V3

A

B

SW

Battery

1

2

GND

3

4

5A

6B

7 SW

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
Heltec WiFi Kit 32 V3

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
MISO

SCK

MOSI

CS

+5V

3V3

GND

SD card holder

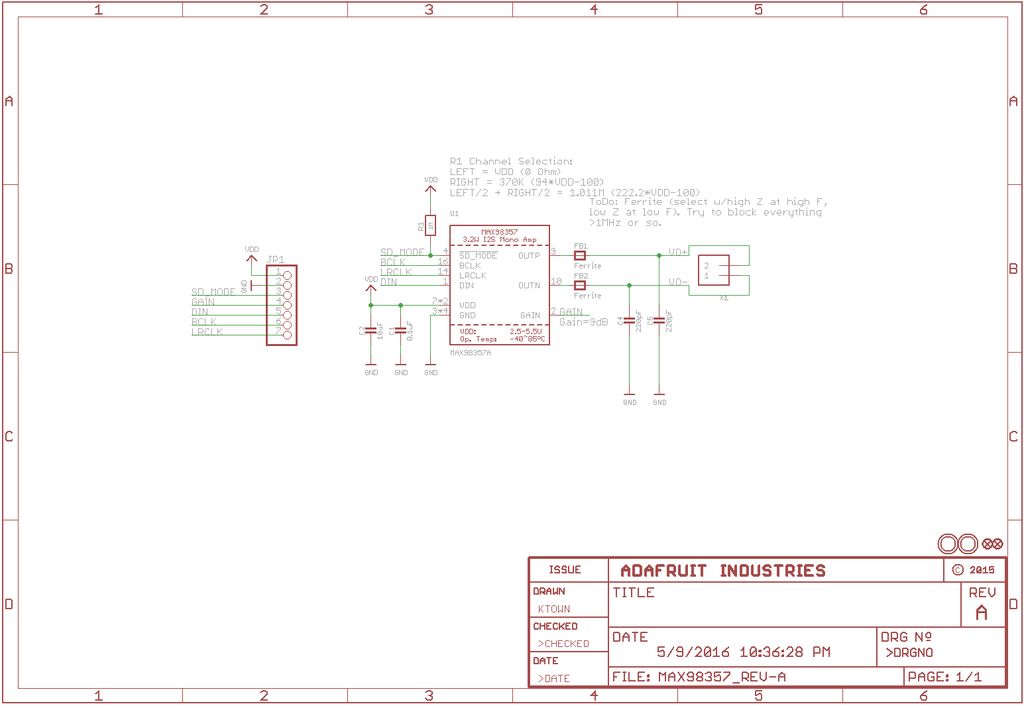
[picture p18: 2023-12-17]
module datasheets/MAX98357A_schematic.png

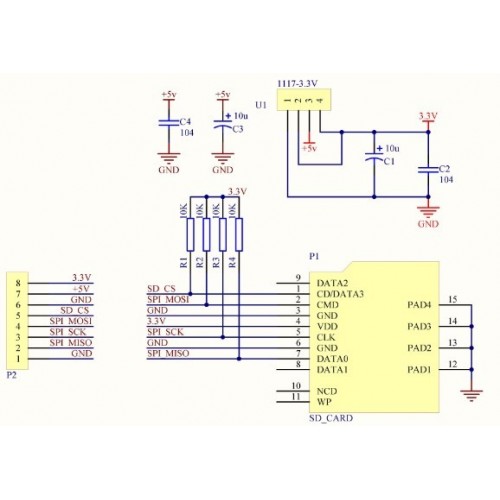
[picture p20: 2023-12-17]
module datasheets/sd_card_holder_schematic.jpg

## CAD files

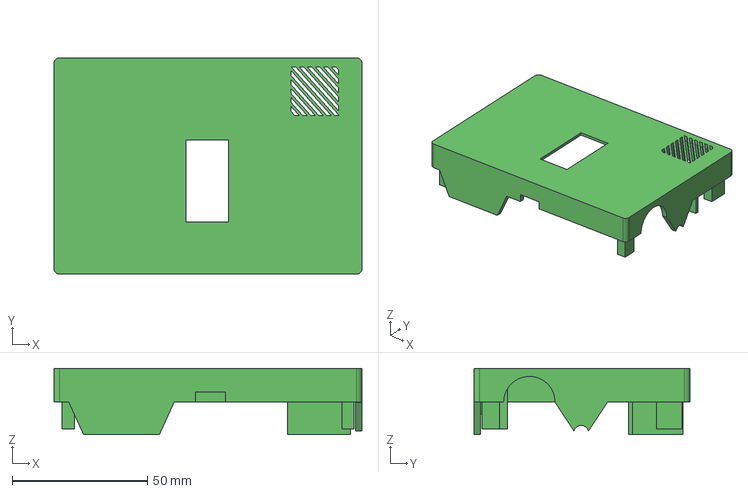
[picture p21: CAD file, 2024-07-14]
case/20240709_Step_Export_Oberteil.step
113.9 x 80.0 x 24.6 mm

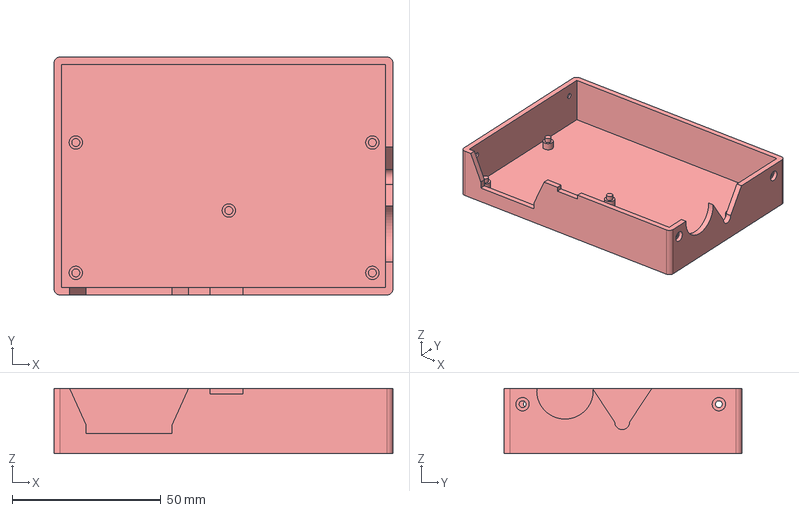
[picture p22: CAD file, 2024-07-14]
case/20240709_Step_Export_Unterteil.step
114.0 x 80.0 x 22.0 mm

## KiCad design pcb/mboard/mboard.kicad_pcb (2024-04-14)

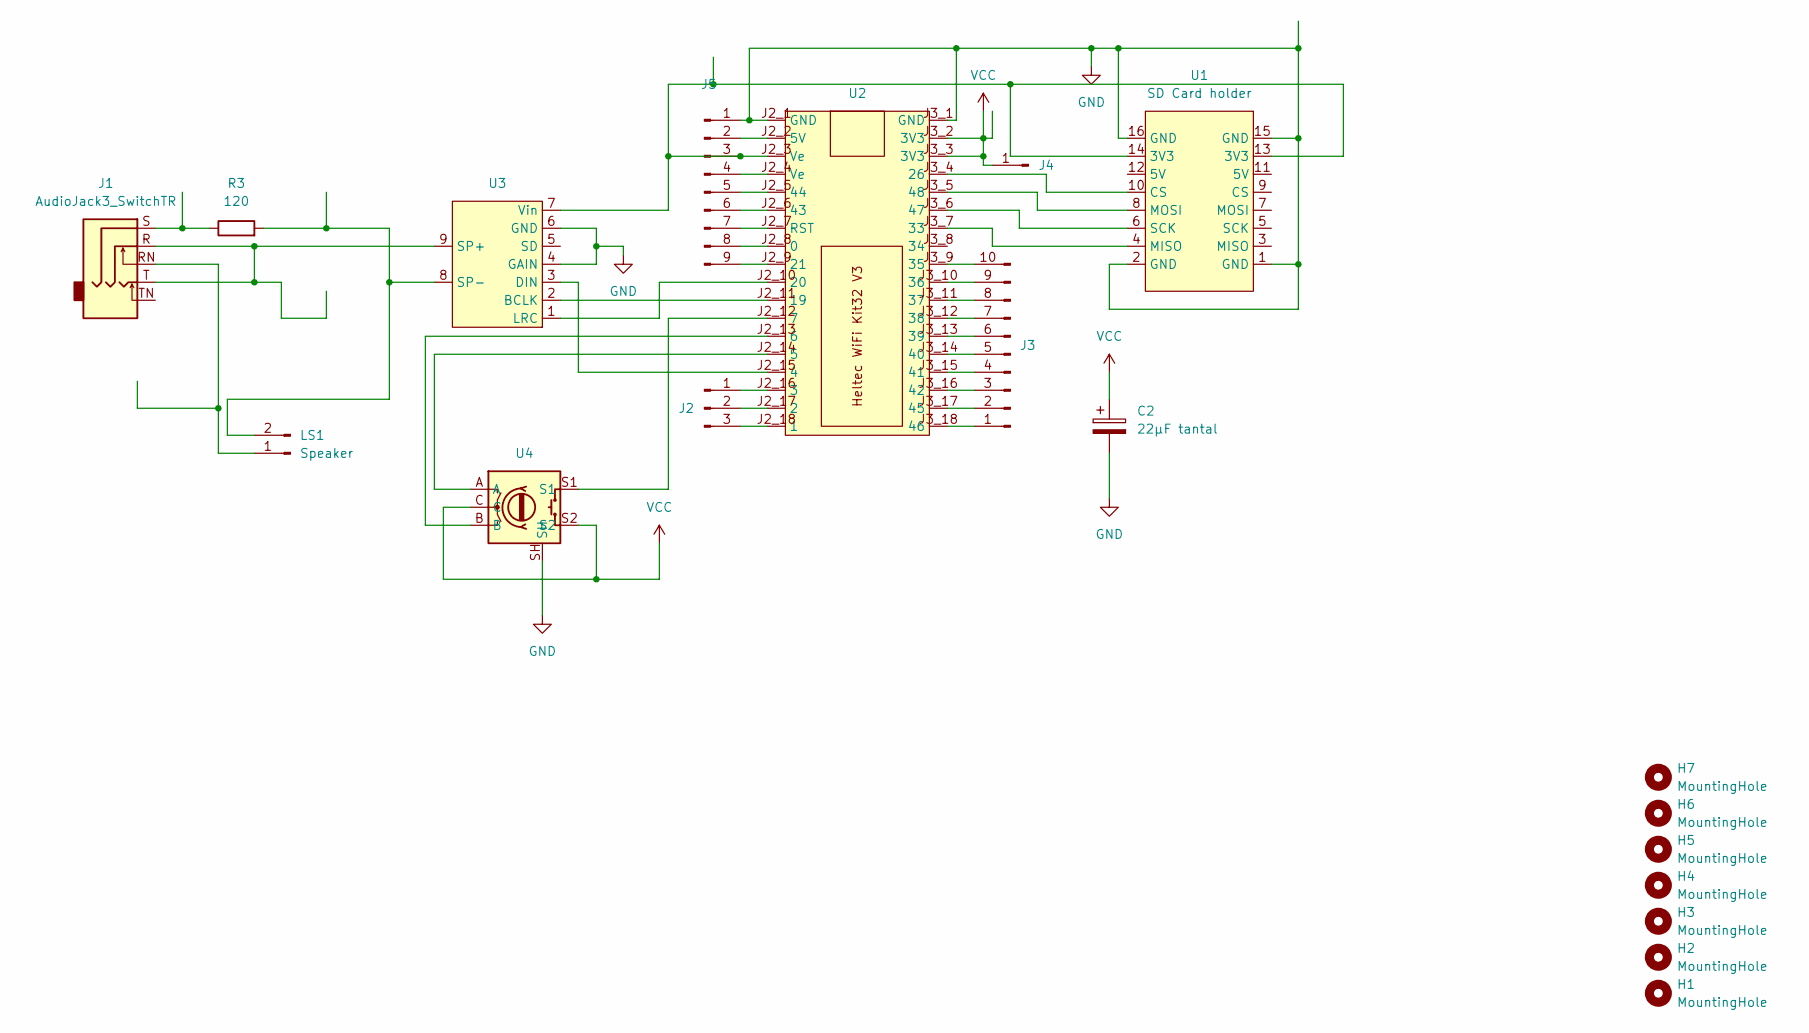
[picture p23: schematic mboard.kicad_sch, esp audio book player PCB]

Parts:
C2: 22µF tantal; CP_Radial_D5.0mm_P2.50mm
H1, H2, H3, H4, H5, H6, H7: MountingHole; MountingHole_2.7mm
J1: AudioJack3_SwitchTR; Jack_3.5mm_CUI_SJ2-3593D-SMT_Horizontal
J2: Conn_01x03_Pin; PinHeader_1x03_P2.54mm_Vertical
J3: Conn_01x10_Pin; PinHeader_1x10_P2.54mm_Vertical
J4: Conn_01x01_Pin; PinHeader_1x01_P2.54mm_Vertical
J5: Conn_01x09_Pin; PinHeader_1x09_P2.54mm_Vertical
LS1: Speaker; PinHeader_1x02_P2.54mm_Vertical
R3: 120; R_Axial_DIN0309_L9.0mm_D3.2mm_P15.24mm_Horizontal
U1: SD Card holder; SD_CARD_HOLDER_1
U2: Heltec WiFi Kit32 V3
U3: MAX98357A_BREAKOUT
U4: PEC16

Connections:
GND: C2.2, J5.1, U1.1 (GND), U1.2 (GND), U1.15 (GND), U1.16 (GND), U2.J2_1 (GND), U2.J3_1 (GND), U3.4 (GAIN), U3.6 (GND), U4.SH
unnamed: J1.S, R3.1
unnamed: J2.1, U2.J2_16 (3)
unnamed: J2.2, U2.J2_17 (2)
unnamed: J2.3, U2.J2_18 (1)
unnamed: J3.1, U2.J3_18 (46)
unnamed: J3.2, U2.J3_17 (45)
unnamed: J3.3, U2.J3_16 (42)
unnamed: J3.4, U2.J3_15 (41)
unnamed: J3.5, U2.J3_14 (40)
unnamed: J3.6, U2.J3_13 (39)
unnamed: J3.7, U2.J3_12 (38)
unnamed: J3.8, U2.J3_11 (37)
unnamed: J3.9, U2.J3_10 (36)
unnamed: J3.10, U2.J3_9 (35)
unnamed: J5.2, U2.J2_2 (5V)
unnamed: J5.3, U1.13 (3V3), U1.14 (3V3), U2.J2_3 (Ve), U3.7 (Vin)
unnamed: J5.4, U2.J2_4 (Ve)
unnamed: J5.5, U2.J2_5 (44)
unnamed: J5.6, U2.J2_6 (43)
unnamed: J5.7, U2.J2_7 (RST)
unnamed: J5.8, U2.J2_8 (0)
unnamed: J5.9, U2.J2_9 (21)
unnamed: J1.RN, LS1.1
unnamed: LS1.2, R3.2, U3.8 (SP-)
unnamed: U2.J2_15 (4), U3.3 (DIN)
unnamed: U2.J2_14 (5), U4.A
unnamed: U2.J2_13 (6), U4.B
unnamed: U2.J2_12 (7), U4.S1
unnamed: U2.J2_11 (19), U3.2 (BCLK)
unnamed: U2.J2_10 (20), U3.1 (LRC)
unnamed: U1.10 (CS), U2.J3_4 (26)
unnamed: U1.4 (MISO), U2.J3_7 (33)
unnamed: U1.6 (SCK), U2.J3_6 (47)
unnamed: U1.8 (MOSI), U2.J3_5 (48)
unnamed: J1.R, J1.T, U3.9 (SP+)
VCC: C2.1, J4.1, U2.J3_2 (3V3), U2.J3_3 (3V3), U4.C, U4.S2

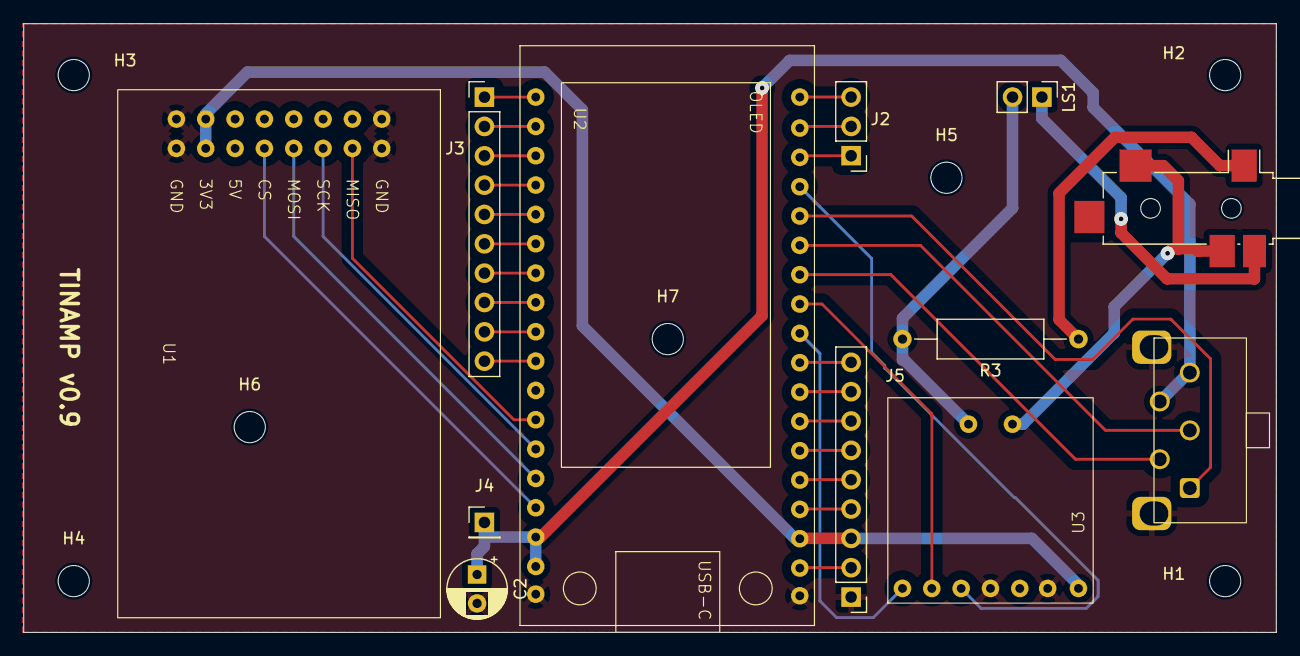
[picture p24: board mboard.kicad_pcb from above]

Board: 2 copper layers, 108.5 x 52.7 mm, 19 parts (0 on the bottom side), 37 nets.

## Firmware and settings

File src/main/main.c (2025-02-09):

/*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
    You should have received a copy of the GNU General Public License
    along with this program.  If not, see <http://www.gnu.org/licenses/>.
*/

//ffmpeg -i input.m4a -c:a copy -movflags +faststart output.m4a

/** Generating a working pre sorted folder index on root of sd card:
  * find * -type d -print |sort | iconv -t 437 > presorted.txt
  */ 
#include <string.h>
#include <sys/unistd.h>
#include <sys/stat.h>
#include "soc/rtc.h"
#include "esp_log.h"
#include "esp_wifi.h"
#include "esp_task_wdt.h"
#include "soc/rtc_cntl_reg.h"

#include "esp_sleep.h"
#include "driver/rtc_io.h"

#include "sd_play.h"
#include "ui_main.h"


#define MAIN_WATCHDOG_TIMEOUT 1000
#define MAIN_LOG_TAG "MAIN"

#define WAKEUP_PIN 7
void MAIN_deep_sleep(){
    gpio_set_level(36,1);//disable vext devices
    gpio_set_level(37,1);//disable ADC batt input

    esp_sleep_pd_config(ESP_PD_DOMAIN_RTC_PERIPH, ESP_PD_OPTION_ON);//leave pulldowns active even if in deep sleep
    ESP_LOGI(MAIN_LOG_TAG,"Pulldown Enable: %i",rtc_gpio_pulldown_en(WAKEUP_PIN));//enable pulldown on wakeup pin which is connected to button of rotary encoder
    ESP_LOGI(MAIN_LOG_TAG,"Wakupeset: %i",esp_sleep_enable_ext1_wakeup(1<<WAKEUP_PIN,ESP_EXT1_WAKEUP_ANY_HIGH)); //1 = High, 0 = Low, enable wakeup on ext1
    if(UI_MAIN_getWakeupTimer()>0){//should the device also wakeup by a setup wakeup timer?
        if(esp_sleep_enable_timer_wakeup(1000000ull*UI_MAIN_getWakeupTimer())==ESP_OK){
            ESP_LOGI(MAIN_LOG_TAG,"Timerwakeup set ok %llu",1000000ull*UI_MAIN_getWakeupTimer());
        }else{
            ESP_LOGE(MAIN_LOG_TAG,"Timerwakeup setup ERROR %llu",1000000ull*UI_MAIN_getWakeupTimer());
        }
    }
    vTaskDelay(pdTICKS_TO_MS(10));//leave some time for the pulldowns to stabilize the voltage
    esp_deep_sleep_start();
}
//displays stack sizes of freertos on terminal
void getStack(void)
{
    TaskStatus_t *pxTaskStatusArray;
    volatile UBaseType_t uxArraySize, x;
    unsigned long ulTotalRunTime;

   /* Take a snapshot of the number of tasks in case it changes while this
   function is executing. */
   uxArraySize = uxTaskGetNumberOfTasks();

   /* Allocate a TaskStatus_t structure for each task.  An array could be
   allocated statically at compile time. */
   pxTaskStatusArray = pvPortMalloc( uxArraySize * sizeof( TaskStatus_t ) );

   if( pxTaskStatusArray != NULL )
   {
      /* Generate raw status information about each task. */
      uxArraySize = uxTaskGetSystemState( pxTaskStatusArray,
                                 uxArraySize,
                                 &ulTotalRunTime );
      for( x = 0; x < uxArraySize; x++ )
      {
         ESP_LOGI(MAIN_LOG_TAG, "%s %lu",pxTaskStatusArray[ x ].pcTaskName,pxTaskStatusArray[ x ].usStackHighWaterMark);
      }
      /* The array is no longer needed, free the memory it consumes. */
      vPortFree( pxTaskStatusArray );
   }
}



void app_main(void)
{
    uint8_t startUpFlags=0;
    esp_task_wdt_config_t wdtConfig;
    wdtConfig.timeout_ms=MAIN_WATCHDOG_TIMEOUT;
    wdtConfig.idle_core_mask=3;//monitor all 2 cores
    wdtConfig.trigger_panic=true;
    esp_task_wdt_reconfigure(&wdtConfig); //reconfigure watchdog with panic handler for both CPUs
    
    if(rtc_clk_slow_src_get()!=SOC_RTC_SLOW_CLK_SRC_XTAL32K){
        ESP_LOGW(MAIN_LOG_TAG,"Not using external 32khz crystal for timed wakeup.");
    }else{
        ESP_LOGI(MAIN_LOG_TAG,"Using external 32khz crystal for timed wakeup.");
    }

    //disable brownout as it might trigger for hungry devices on Vext pin, e.g. bigger SD cards
    uint32_t brownOutValue=READ_PERI_REG(RTC_CNTL_BROWN_OUT_REG);
    brownOutValue&=~RTC_CNTL_BROWN_OUT_ENA;//disable
    WRITE_PERI_REG(RTC_CNTL_BROWN_OUT_REG, brownOutValue);

    SD_PLAY_init();

    //switch Vext pin on
    esp_rom_gpio_pad_select_gpio(36);
    gpio_set_direction(36, GPIO_MODE_OUTPUT);
    gpio_set_level(36,0);//power Vext devices

    UI_MAIN_init();
    esp_wifi_stop(); //we do not need wifi at all
    SD_PLAY_startService();

    //display and react to type of wakeup
    esp_sleep_wakeup_cause_t wakeupCause=esp_sleep_get_wakeup_cause();
    ESP_LOGI(MAIN_LOG_TAG,"Wakeupcause: %i",wakeupCause);
    if(wakeupCause==ESP_SLEEP_WAKEUP_TIMER){
        ESP_LOGI(MAIN_LOG_TAG,"Wakeup by timer");
        startUpFlags|=UI_MAIN_STARTUPFLAG_RTC;
    }else if(wakeupCause==ESP_SLEEP_WAKEUP_EXT1){
        ESP_LOGI(MAIN_LOG_TAG,"Wakeup by button press");
        startUpFlags|=UI_MAIN_STARTUPFLAG_MANUAL;
    }
    if(UI_MAIN_isImagePersisted()){
        startUpFlags|=UI_MAIN_STARTUPFLAG_IMAGE_PERSISTED;
    }
    UI_MAIN_run(startUpFlags);

    UI_MAIN_deInit();

    while(1){
        MAIN_deep_sleep();
    }
}

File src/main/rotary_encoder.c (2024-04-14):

/*
 * Copyright (c) 2019 David Antliff
 * Copyright 2011 Ben Buxton
 *
 * This file is part of the esp32-rotary-encoder component.
 *
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
 * You should have received a copy of the GNU General Public License
 * along with esp32-rotary-encoder.  If not, see <https://www.gnu.org/licenses/>.
 */

/**
 * @file rotary_encoder.c
 * @brief Driver implementation for the ESP32-compatible Incremental Rotary Encoder component.
 *
 * Based on https://github.com/buxtronix/arduino/tree/master/libraries/Rotary
 * Original header follows:
 *
 * Rotary encoder handler for arduino. v1.1
 *
 * Copyright 2011 Ben Buxton. Licenced under the GNU GPL Version 3.
 * Contact: bb@cactii.net
 *
 * A typical mechanical rotary encoder emits a two bit gray code
 * on 3 output pins. Every step in the output (often accompanied
 * by a physical 'click') generates a specific sequence of output
 * codes on the pins.
 *
 * There are 3 pins used for the rotary encoding - one common and
 * two 'bit' pins.
 *
 * The following is the typical sequence of code on the output when
 * moving from one step to the next:
 *
 *   Position   Bit1   Bit2
 *   ----------------------
 *     Step1     0      0
 *      1/4      1      0
 *      1/2      1      1
 *      3/4      0      1
 *     Step2     0      0
 *
 * From this table, we can see that when moving from one 'click' to
 * the next, there are 4 changes in the output code.
 *
 * - From an initial 0 - 0, Bit1 goes high, Bit0 stays low.
 * - Then both bits are high, halfway through the step.
 * - Then Bit1 goes low, but Bit2 stays high.
 * - Finally at the end of the step, both bits return to 0.
 *
 * Detecting the direction is easy - the table simply goes in the other
 * direction (read up instead of down).
 *
 * To decode this, we use a simple state machine. Every time the output
 * code changes, it follows state, until finally a full steps worth of
 * code is received (in the correct order). At the final 0-0, it returns
 * a value indicating a step in one direction or the other.
 *
 * It's also possible to use 'half-step' mode. This just emits an event
 * at both the 0-0 and 1-1 positions. This might be useful for some
 * encoders where you want to detect all positions.
 *
 * If an invalid state happens (for example we go from '0-1' straight
 * to '1-0'), the state machine resets to the start until 0-0 and the
 * next valid codes occur.
 *
 * The biggest advantage of using a state machine over other algorithms
 * is that this has inherent debounce built in. Other algorithms emit spurious
 * output with switch bounce, but this one will simply flip between
 * sub-states until the bounce settles, then continue along the state
 * machine.
 * A side effect of debounce is that fast rotations can cause steps to
 * be skipped. By not requiring debounce, fast rotations can be accurately
 * measured.
 * Another advantage is the ability to properly handle bad state, such
 * as due to EMI, etc.
 * It is also a lot simpler than others - a static state table and less
 * than 10 lines of logic.
 */

#include "rotary_encoder.h"

#include "esp_log.h"
#include "driver/gpio.h"

#define TAG "rotary_encoder"

//#define ROTARY_ENCODER_DEBUG

// Use a single-item queue so that the last value can be easily overwritten by the interrupt handler
#define EVENT_QUEUE_LENGTH 1

#define TABLE_ROWS 7

#define DIR_NONE 0x0   // No complete step yet.
#define DIR_CW   0x10  // Clockwise step.
#define DIR_CCW  0x20  // Anti-clockwise step.

// Create the half-step state table (emits a code at 00 and 11)
#define R_START       0x0
#define H_CCW_BEGIN   0x1
#define H_CW_BEGIN    0x2
#define H_START_M     0x3
#define H_CW_BEGIN_M  0x4
#define H_CCW_BEGIN_M 0x5

static const uint8_t _ttable_half[TABLE_ROWS][TABLE_COLS] = {
    // 00                  01              10            11                   // BA
    {H_START_M,            H_CW_BEGIN,     H_CCW_BEGIN,  R_START},            // R_START (00)
    {H_START_M | DIR_CCW,  R_START,        H_CCW_BEGIN,  R_START},            // H_CCW_BEGIN
    {H_START_M | DIR_CW,   H_CW_BEGIN,     R_START,      R_START},            // H_CW_BEGIN
    {H_START_M,            H_CCW_BEGIN_M,  H_CW_BEGIN_M, R_START},            // H_START_M (11)
    {H_START_M,            H_START_M,      H_CW_BEGIN_M, R_START | DIR_CW},   // H_CW_BEGIN_M
    {H_START_M,            H_CCW_BEGIN_M,  H_START_M,    R_START | DIR_CCW},  // H_CCW_BEGIN_M
};

// Create the full-step state table (emits a code at 00 only)
#  define F_CW_FINAL  0x1
#  define F_CW_BEGIN  0x2
#  define F_CW_NEXT   0x3
#  define F_CCW_BEGIN 0x4
#  define F_CCW_FINAL 0x5
#  define F_CCW_NEXT  0x6

static const uint8_t _ttable_full[TABLE_ROWS][TABLE_COLS] = {
    // 00        01           10           11                  // BA
    {R_START,    F_CW_BEGIN,  F_CCW_BEGIN, R_START},           // R_START
    {F_CW_NEXT,  R_START,     F_CW_FINAL,  R_START | DIR_CW},  // F_CW_FINAL
    {F_CW_NEXT,  F_CW_BEGIN,  R_START,     R_START},           // F_CW_BEGIN
    {F_CW_NEXT,  F_CW_BEGIN,  F_CW_FINAL,  R_START},           // F_CW_NEXT
    {F_CCW_NEXT, R_START,     F_CCW_BEGIN, R_START},           // F_CCW_BEGIN
    {F_CCW_NEXT, F_CCW_FINAL, R_START,     R_START | DIR_CCW}, // F_CCW_FINAL
    {F_CCW_NEXT, F_CCW_FINAL, F_CCW_BEGIN, R_START},           // F_CCW_NEXT
};

static uint8_t _process(rotary_encoder_info_t * info)
{
    uint8_t event = 0;
    if (info != NULL)
    {
        // Get state of input pins.
        uint8_t pin_state = (gpio_get_level(info->pin_b) << 1) | gpio_get_level(info->pin_a);

        // Determine new state from the pins and state table.
        uint8_t old_state = info->table_state;


        info->table_state = info->table[info->table_state & 0xf][pin_state];

        // Return emit bits, i.e. the generated event.
        event = info->table_state & 0x30;

#ifdef ROTARY_ENCODER_DEBUG
        ESP_EARLY_LOGI(TAG, "BA %d%d, state 0x%02x, new state 0x%02x, event 0x%02x",
                       pin_state >> 1, pin_state & 1, old_state, info->table_state, event);
#endif
    }
    return event;
}

uint8_t rotary_encoder_use_dir_flip=0;
uint8_t rotary_encoder_use_skip=0;
uint8_t rotary_encoder_cw_skip=0;
uint8_t rotary_encoder_ccw_skip=0;
uint8_t rotary_encoder_lastDirection=0;

void rotary_encoder_set_direction(uint8_t dir){
    if(dir){
        rotary_encoder_use_dir_flip=1;
    }else{
        rotary_encoder_use_dir_flip=0;
    }
}

void rotary_encoder_set_speed(uint8_t speed){
    if(speed){
        rotary_encoder_use_skip=1;
    }else{
        rotary_encoder_use_skip=0;
    }
}

uint8_t rotary_encoder_get_direction(){
    return rotary_encoder_use_dir_flip;
}
uint8_t rotary_encoder_get_speed(){
    return rotary_encoder_use_skip;
}
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

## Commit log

2023-12-17 added sources
    [partitions.csv]
2023-12-21 added current measurements and PCB pictures
2023-12-30 added volume fadeout for sleep timer, added wake up timer using RTC, faster sorting by increasing CPU speed shortly, documentation of public .h files, videos for firmware upgrade and wake up timer us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
    [battery.c, main.c, rotary_encoder.c]
2024-01-11 resetting of i2s only if not yet setup correctly to avoid DACs pops volume=7500 now means 100% source volume, volume=10000 now means 125% source volume optimized pipeline VolumeFilter buffer size for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
    [mboard.kicad_pcb, mboard.kicad_sch]
2024-04-14 added global settings menu added new settings: screen rotation, rotary encoder speed and direction more documentation
    [mboard.kicad_pcb, mboard.kicad_sch, mboard.step]
2024-04-28 - moved sleep timer to play overlay menu - show countdown for play overlay sub menu reset - allow deletion of bookmarks via global settings - display number of bookmarks in shutdown screen
    [saves.c, screens.c, ui_elements.c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]
2024-07-14 - added brightness settings - first POC of 3d case model (good for testing but definitely not the final one)
    [20240709_Step_Export_Oberteil.step, 20240709_Step_Export_Unterteil.step]
2024-11-26 fixed uint32_t overflow bug with sleep timer >72min default to seek time mode for one chapter audio books
    [screens.c, ui_main.c]
2024-12-08 - fixed bug introduced with 00.00.0A when entering an audio book for the first time with 1 book initially is not seekable - fixed AMR bitrate detection - fixed bug displaying wrong play position info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
    [sd_play.c, ui_main.c]
2025-01-02 SDK Updates, new features, bugfixes - updated espressif sdk versions to idf v5.3.2, adf v2.7 - fixed mpeg version 2 layer 3 format handling - now showing bookmark hint in book selection screen - redu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
    [battery.c, board_pins_config.c, main.c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]

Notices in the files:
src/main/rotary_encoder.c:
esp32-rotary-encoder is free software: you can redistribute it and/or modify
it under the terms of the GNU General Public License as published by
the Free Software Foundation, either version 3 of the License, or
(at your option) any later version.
